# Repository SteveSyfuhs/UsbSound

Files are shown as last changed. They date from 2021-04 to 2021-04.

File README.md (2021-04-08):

# Usb Sound
 A custom-made USB sound card for Balanced Audio.

# Why?

My current USB DAC isn't great and instead of just buying a new one I thought I'd try and waste some serious engineering hours learning how to build one instead.

# What's wrong with the current DAC?

My existing DAC uses the [PCM2705](https://www.ti.com/lit/ds/symlink/pcm2705.pdf) chip to handle both the USB and DAC side of things. It's fine, I guess, but it has some annoying quirks.

First, you have to bolt on an additional chip to do silly things like control the USB descriptors. Absent that you're left with this annoying string with two trailing spaces (probably nulls?). Clearly not the end of the world, but I might as well aim for perfect.



Second, the output from the chip is only single-ended so it requires extra effort to make a _good_ differential output. This existing device is using a transformer (two, on per channel) to generate the differential pair, which is great for isolation, but transformers are notorious for distortion at high frequency. 

Curiously this device also doesn't produce a great differential output at 1000hz.



Channel A (blue) is the positive leg and Channel B (red) is the negative leg. Channel 3 (magenta?) is A+B, which ideally should sum to zero, not ~16mV RMS.

# Why are you using X?

To be clear: I really have no idea what I'm doing so my choice of parts or circuit are driven by the last thing I learned about. If there's clearly a better way to do something then please let me know.

### Why the STM32F4 Micro?

It happened to be the chip used in [Phil's video](https://www.youtube.com/watch?v=C7-8nUU6e3E) where learned to use Kicad and it happens to support I2S. It's incredibly powerful for the use case here, and a less powerful device could be used instead. That said, it could make for a useful platform for building out digital filters and stuff.

### Why the [PCM1795](https://www.ti.com/lit/ds/symlink/pcm1795.pdf) DAC?

I like the low distortion and noise floor it provides and since I'm starting with a blank canvas why not start with something that's overkill? I can only make it worse.

Note: the _audible_ differences between this and other DACs is ultimately going to be nil so there will be no notable benefit. I'm doing this because I can.

### Why the [NE5524](https://www.ti.com/lit/ds/symlink/ne5534.pdf) Op-Amps?

The PCM1795 uses that as a baseline for the measured circuits so it's a helpful starting place. I will probably switch these out for [LM4562's](https://www.ti.com/lit/ds/symlink/lm4562.pdf) in the near future once I test out the board and do initial measurements to compare against spec. The LM4562s have lower distortion and noise floor, and more interestingly contain two op-amps in the package so I can reduce the circuit footprint.

Again, I can only make things worse.

### Why Balanced Audio?

The speakers I'll be driving are studio monitors and they require a balanced XLR connection.

## Are you going to support multiple output channels?

Eventually, probably. The micro supports 3 I2S lines, and each I2S line supports two channels out and one in.

## Are you going to support audio in?

Maybe. See the output section.

## What's the driver story?

Ideally it'll show up as a USB audio device and all major operating systems will just pick it up.

# Measurement Methodology

A work in progress. Ideal testing should measure:

 * Noise - Specifically what the device adds to the signal.
 * Distortion - Specifically how the device modifies the signal integrity across the device bandwidth.
 * Flatness - Specifically whether the device has amplified or attenuated voltage across the device bandwidth.

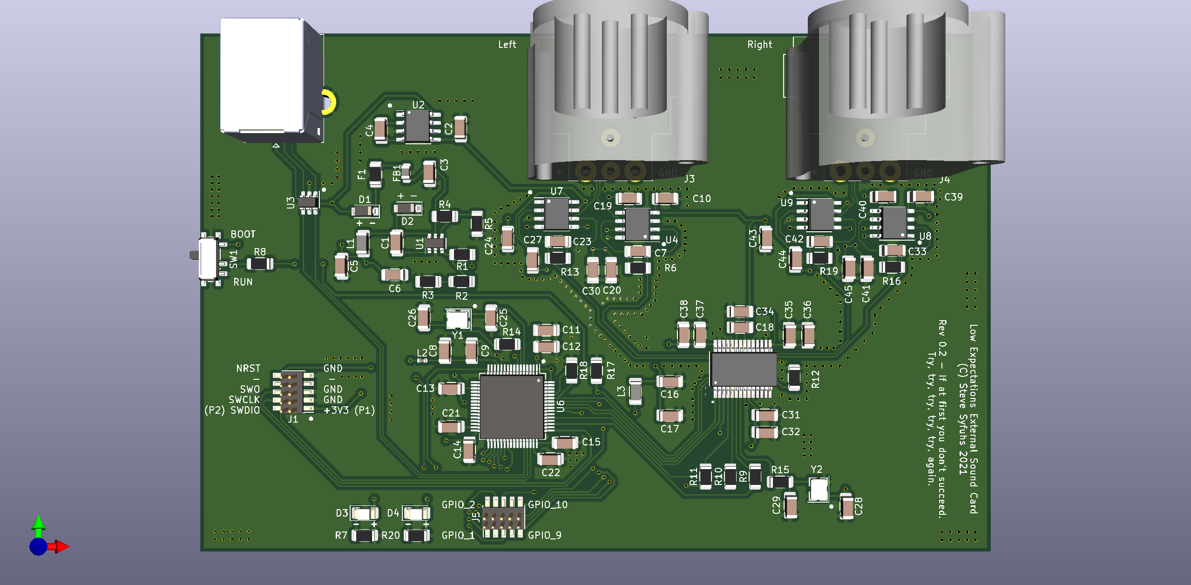
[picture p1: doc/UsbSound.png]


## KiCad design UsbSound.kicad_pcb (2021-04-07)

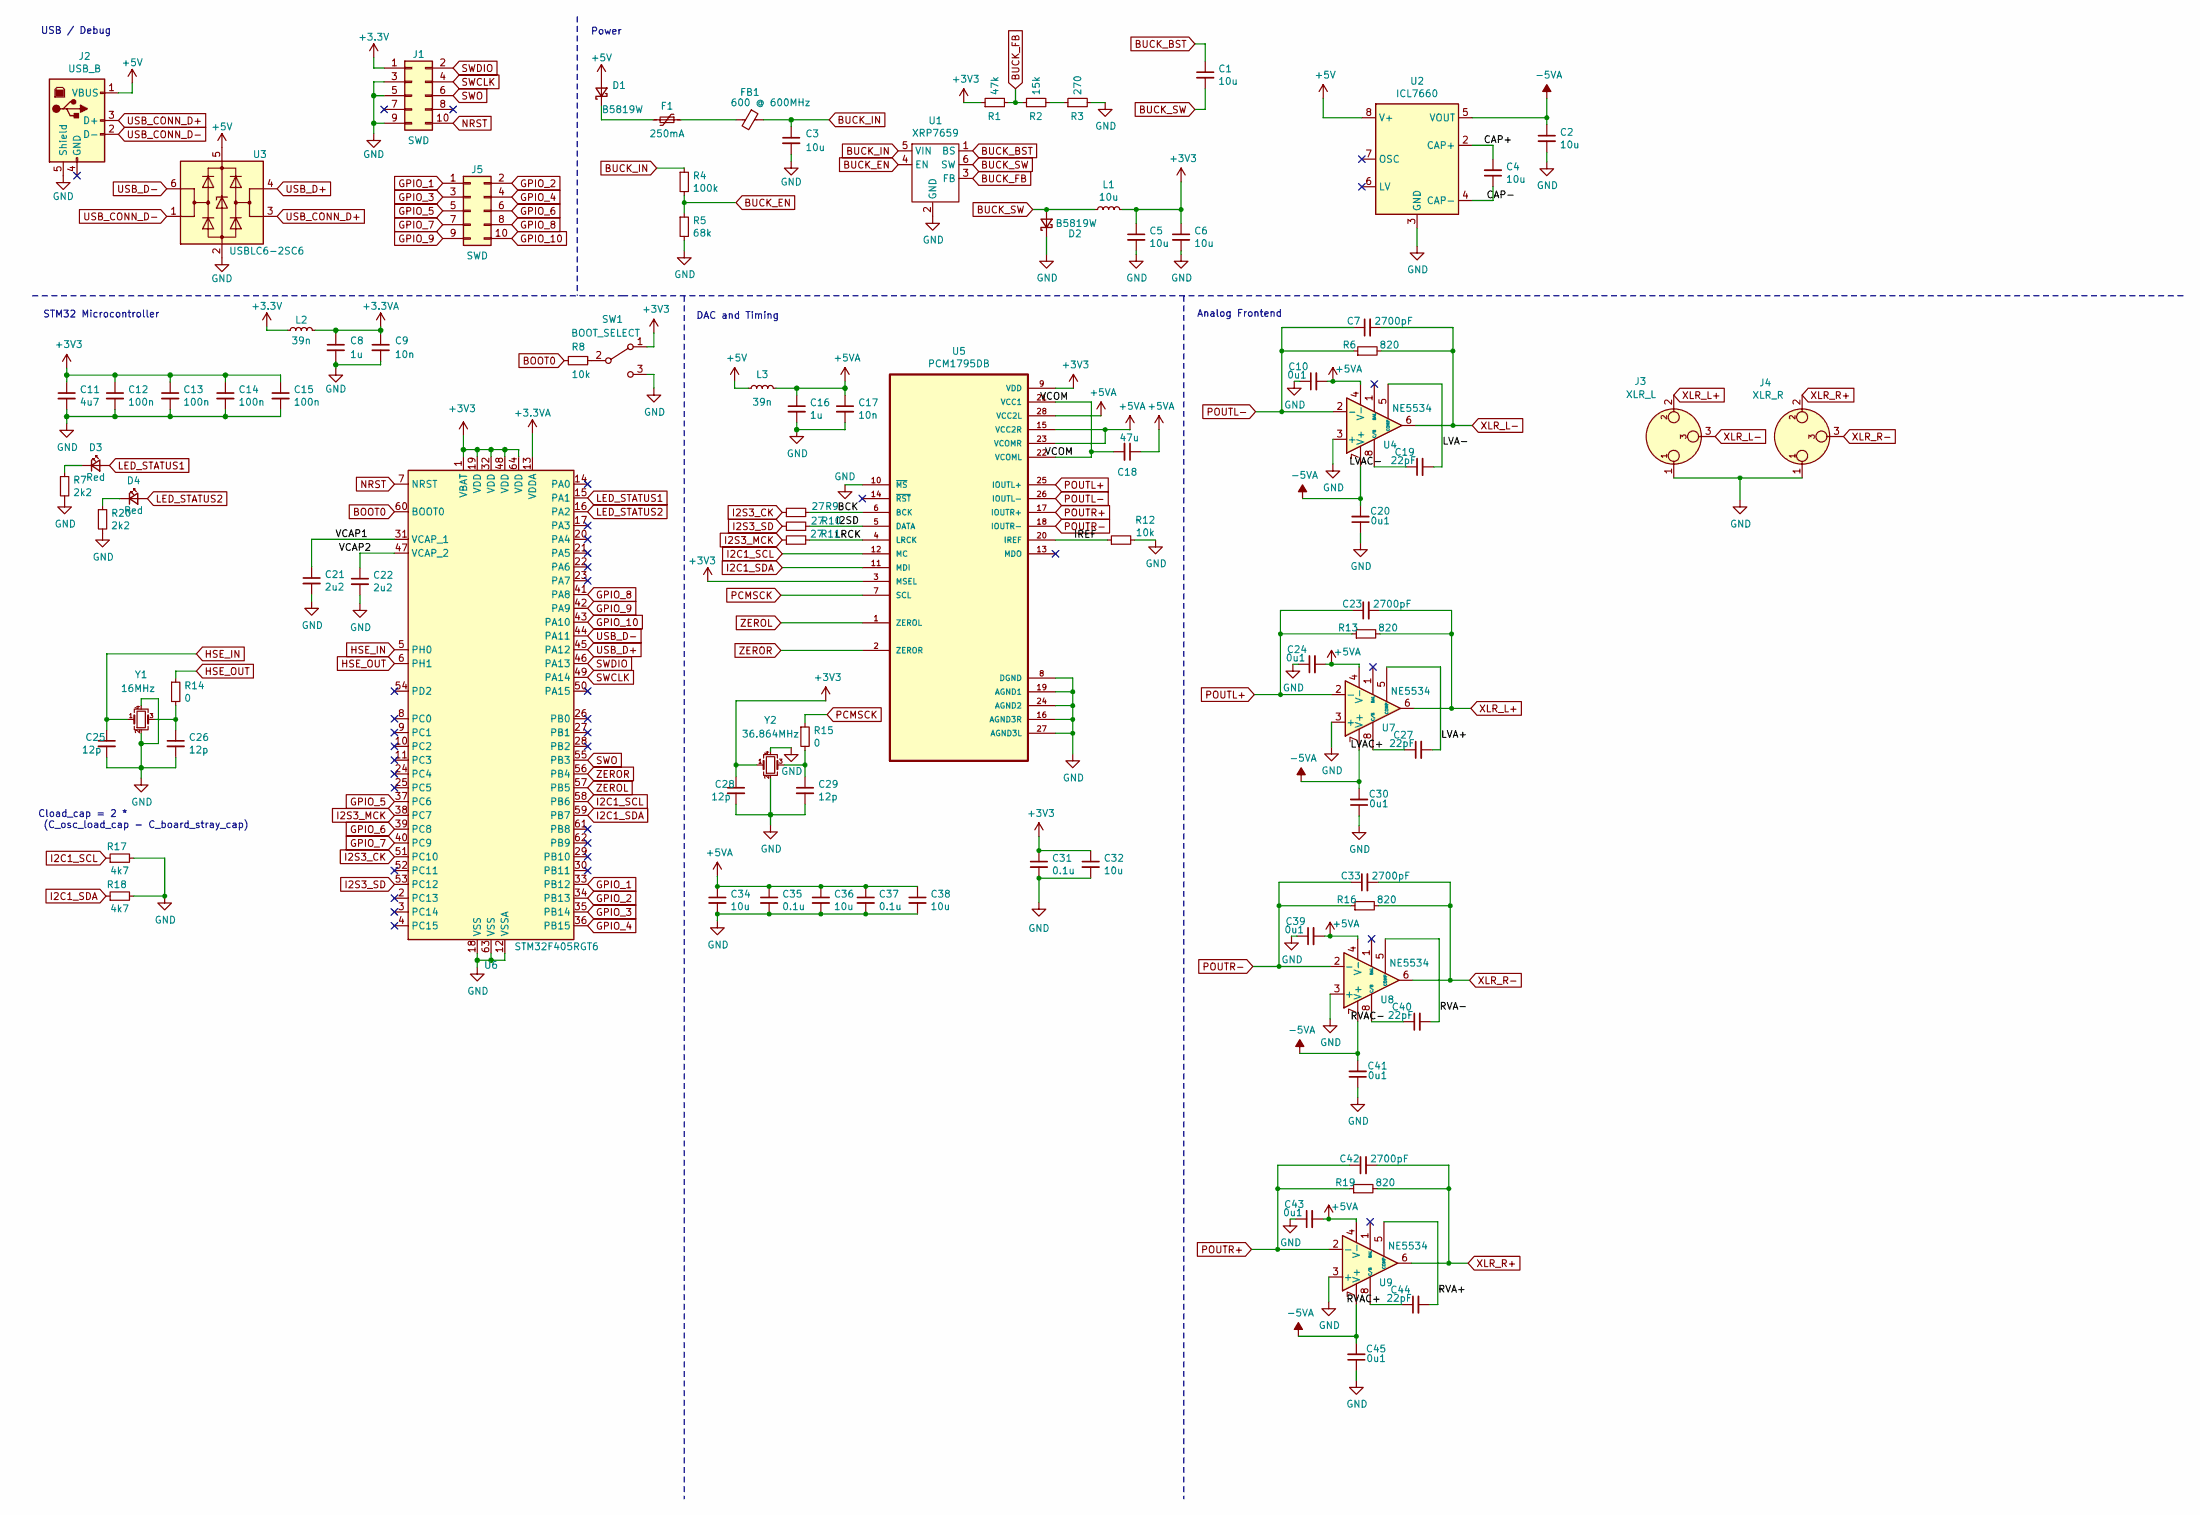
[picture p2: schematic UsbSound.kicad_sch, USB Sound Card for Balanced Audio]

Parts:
C1, C2, C4, C5, C6, C32, C34, C36, C38: 10u; C_1206_3216Metric
C3: 10u; C_1206_3216Metric; LCSC Part # C13585
C7, C23, C33, C42: 2700pF; C_1206_3216Metric
C8: 1u; C_1206_3216Metric; LCSC Part # C52923
C9: 10n; C_1206_3216Metric; LCSC Part # C15195
C10, C20, C24, C30, C39, C41, C43, C45: 0u1; C_1206_3216Metric
C11: 4u7; C_1206_3216Metric
C12, C13, C14, C15: 100n; C_1206_3216Metric
C16: 1u; C_1206_3216Metric
C17: 10n; C_1206_3216Metric
C18: 47u; C_1206_3216Metric
C19, C27, C40, C44: 22pF; C_1206_3216Metric
C21, C22: 2u2; C_1206_3216Metric
C25, C26, C28, C29: 12p; C_1206_3216Metric
C31, C35, C37: 0.1u; C_1206_3216Metric
D1: B5819W; D_SOD-123; LCSC Part # C8598
D2: B5819W; D_SOD-123
D3, D4: Red; LED_1206_3216Metric
F1: 250mA; Fuse_1206_3216Metric; LCSC Part # C369159
FB1: 600 @ 600MHz; L_0805_2012Metric; LCSC Part # C1017
J1, J5: SWD; PinHeader_2x05_P1.27mm_Vertical_SMD
J2: USB_B; USB_B_Lumberg_2411_02_Horizontal
J3: XLR_L; Jack_XLR_Neutrik_NC3MAH_Horizontal
J4: XLR_R; Jack_XLR_Neutrik_NC3MAH_Horizontal
L1: 10u; L_1206_3216Metric
L2: 39n; L_0402_1005Metric; LCSC Part # C26443
L3: 39n; L_1206_3216Metric
R1: 47k; R_1206_3216Metric
R2: 15k; R_1206_3216Metric
R3: 270; R_1206_3216Metric
R4: 100k; R_1206_3216Metric
R5: 68k; R_1206_3216Metric
R6, R13, R16, R19: 820; R_1206_3216Metric
R7, R20: 2k2; R_1206_3216Metric
R8, R12: 10k; R_1206_3216Metric
R9, R10, R11: 27; R_1206_3216Metric
R14, R15: 0; R_1206_3216Metric
R17, R18: 4k7; R_1206_3216Metric
SW1: BOOT_SELECT; SW_SPDT_PCM12
U1: XRP7659; TSOP-6_1.65x3.05mm_P0.95mm
U2: ICL7660; SOIC-8-1EP_3.9x4.9mm_P1.27mm_EP2.29x3mm
U3: USBLC6-2SC6; SOT-23-6; LCSC Part # C7519
U4, U7, U8, U9: NE5534; SOIC-8-1EP_3.9x4.9mm_P1.27mm_EP2.29x3mm
U5: PCM1795DB; SOP65P780X200-28N
U6: STM32F405RGT6; LQFP-64_10x10mm_P0.5mm
Y1: 16MHz; Crystal_SMD_3225-4Pin_3.2x2.5mm
Y2: 36.864MHz; Crystal_SMD_3225-4Pin_3.2x2.5mm

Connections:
+3.3VA: C8.1, C9.1, L2.2, U6.13 (VDDA)
+5V: D1.2 (A), J2.1 (VBUS), L3.1, U2.8 (V+), U3.5 (VBUS)
+5VA: C10.2, C16.1, C17.1, C18.1, C24.2, C34.1, C35.1, C36.1, C37.1, C38.1, C39.2, C43.2, L3.2, U4.4 (V-), U5.15 (VCC2R), U5.23 (VCOMR), U5.28 (VCC2L), U7.4 (V-), U8.4 (V-), U9.4 (V-)
-5VA: C2.1, C20.2, C30.2, C41.2, C45.2, U2.5 (VOUT), U4.7 (V+), U7.7 (V+), U8.7 (V+), U9.7 (V+)
/BCK: R9.2, U5.6 (BCK)
/CAP+: C4.2, U2.2 (CAP+)
/CAP-: C4.1, U2.4 (CAP-)
/I2SD: R10.2, U5.5 (DATA)
/IREF: R12.1, U5.20 (IREF)
/LRCK: R11.2, U5.4 (LRCK)
/LVA+: C27.2, U7.5 (COMP)
/LVA-: C19.2, U4.5 (COMP)
/LVAC+: C27.1, U7.8 (C/B)
/LVAC-: C19.1, U4.8 (C/B)
/RVA+: C44.2, U9.5 (COMP)
/RVA-: C40.2, U8.5 (COMP)
/RVAC+: C44.1, U9.8 (C/B)
/RVAC-: C40.1, U8.8 (C/B)
/VCAP1: C21.1, U6.31 (VCAP_1)
/VCAP2: C22.1, U6.47 (VCAP_2)
/VCOM: C18.2, U5.21 (VCC1), U5.22 (VCOML)
BOOT0: R8.2, U6.60 (BOOT0)
BUCK_BST: C1.1, U1.1 (BS)
BUCK_EN: R4.2, R5.1, U1.4 (EN)
BUCK_FB: R1.2, R2.1, U1.3 (FB)
BUCK_IN: C3.1, FB1.1, R4.1, U1.5 (VIN)
BUCK_SW: C1.2, D2.2 (A), L1.1, U1.6 (SW)
GND: C2.2, C3.2, C5.2, C6.2, C8.2, C9.2, C10.1, C11.2, C12.2, C13.2, C14.2, C15.2, C16.2, C17.2, C20.1, C21.2, C22.2, C24.1, C25.2, C26.2, C28.2, C29.2, C30.1, C31.2, C32.2, C34.2, C35.2, C36.2, C37.2, C38.2, C39.1, C41.1, C43.1, C45.1, D2.1 (K), J1.3, J1.5, J1.9, J2.5 (Shield), J3.1, J4.1, R3.2, R5.2, R7.2, R12.2, R17.2, R18.2, R20.2, SW1.3 (C), U1.2 (GND), U2.3 (GND), U3.2 (GND), U4.3 (+), U5.8 (DGND), U5.10 (~MS), U5.16 (AGND3R), U5.19 (AGND1), U5.24 (AGND2), U5.27 (AGND3L), U6.12 (VSSA), U6.18 (VSS), U6.63 (VSS), U7.3 (+), U8.3 (+), U9.3 (+), Y1.2, Y1.4, Y2.2, Y2.4
GPIO_1: J5.1, U6.33 (PB12)
GPIO_2: J5.2, U6.34 (PB13)
GPIO_3: J5.3, U6.35 (PB14)
GPIO_4: J5.4, U6.36 (PB15)
GPIO_5: J5.5, U6.37 (PC6)
GPIO_6: J5.6, U6.39 (PC8)
GPIO_7: J5.7, U6.40 (PC9)
GPIO_8: J5.8, U6.41 (PA8)
GPIO_9: J5.9, U6.42 (PA9)
GPIO_10: J5.10, U6.43 (PA10)
HSE_IN: C25.1, U6.5 (PH0), Y1.1
HSE_OUT: R14.1, U6.6 (PH1)
I2C1_SCL: R17.1, U5.12 (MC), U6.58 (PB6)
I2C1_SDA: R18.1, U5.11 (MDI), U6.59 (PB7)
I2S3_CK: R9.1, U6.51 (PC10)
I2S3_MCK: R11.1, U6.38 (PC7)
I2S3_SD: R10.1, U6.53 (PC12)
LED_STATUS1: D3.2 (A), U6.15 (PA1)
LED_STATUS2: D4.2 (A), U6.16 (PA2)
NRST: J1.10, U6.7 (NRST)
unnamed: C26.1, R14.2, Y1.3
unnamed: C29.1, R15.2, Y2.3
unnamed: D1.1 (K), F1.2
unnamed: D3.1 (K), R7.1
unnamed: D4.1 (K), R20.1
unnamed: F1.1, FB1.2
unnamed: R2.2, R3.1
unnamed: R8.1, SW1.2 (B)
PCMSCK: R15.1, U5.7 (SCL)
POUTL+: C23.1, R13.1, U5.25 (IOUTL+), U7.2 (-)
POUTL-: C7.1, R6.1, U4.2 (-), U5.26 (IOUTL-)
POUTR+: C42.1, R19.1, U5.17 (IOUTR+), U9.2 (-)
POUTR-: C33.1, R16.1, U5.18 (IOUTR-), U8.2 (-)
SWCLK: J1.4, U6.49 (PA14)
SWDIO: J1.2, U6.46 (PA13)
SWO: J1.6, U6.55 (PB3)
USB_CONN_D+: J2.3 (D+), U3.3 (I/O2)
USB_CONN_D-: J2.2 (D-), U3.1 (I/O1)
USB_D+: U3.4 (I/O2), U6.45 (PA12)
USB_D-: U3.6 (I/O1), U6.44 (PA11)
XLR_L+: C23.2, J3.2, R13.2, U7.6
XLR_L-: C7.2, J3.3, R6.2, U4.6
XLR_R+: C42.2, J4.2, R19.2, U9.6
XLR_R-: C33.2, J4.3, R16.2, U8.6
ZEROL: U5.1 (ZEROL), U6.57 (PB5)
ZEROR: U5.2 (ZEROR), U6.56 (PB4)

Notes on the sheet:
Cload_cap = 2 * (C_osc_load_cap - C_board_stray_cap)
USB / Debug
STM32 Microcontroller
Power
DAC and Timing
Analog Frontend

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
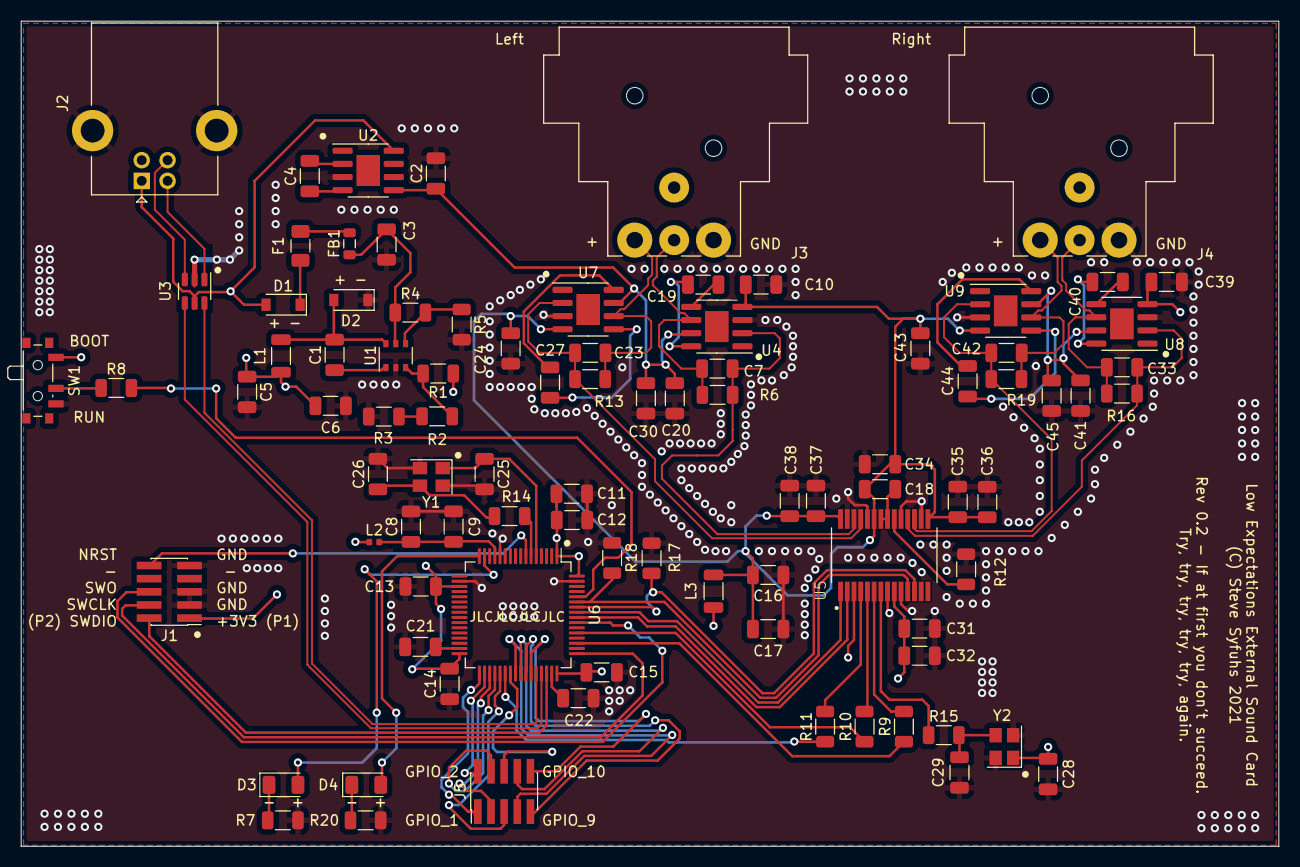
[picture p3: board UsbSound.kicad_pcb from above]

Board: 4 copper layers, 121.6 x 79.8 mm, 91 parts (0 on the bottom side), 75 nets.

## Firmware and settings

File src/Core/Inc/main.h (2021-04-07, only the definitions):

#define ZEROR_Pin GPIO_PIN_4
#define ZEROR_GPIO_Port GPIOB
#define ZEROL_Pin GPIO_PIN_5
#define ZEROL_GPIO_Port GPIOB

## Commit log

2021-03-30 first pass at schematic.
    Basic USB to micro to DAC to XLR stereo.
    DAC clock needs to be added.
    Power rails for opamps maybe should be boosted.
    [UsbSound.kicad_pcb, UsbSound.kicad_sch]
2021-04-01 fixup electrical rules and stupid grids
    Added crystal for PCM clock.
    Added footprints for most components.
    [UsbSound.kicad_sch]
2021-04-03 First rev of board is done
    If at first you don't succeed... try...try...try...try...try...try...try...try...
    [UsbSound.kicad_pcb, UsbSound.kicad_sch]
2021-04-03 Added rev 0.1 fabrication files
    [UsbSound-B_Cu.gbr, UsbSound-B_Mask.gbr, UsbSound-B_Paste.gbr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]
2021-04-03 Added -5v rail because I'm an idiot and forgot it
    [UsbSound.kicad_pcb, UsbSound.kicad_sch]
2021-04-03 Op Amps are better paired for line matching
    [UsbSound.kicad_pcb]
2021-04-04 Fixing models
    [UsbSound.kicad_pcb, UsbSound.kicad_sch]
2021-04-04 More via stitching and updated image
    [UsbSound.kicad_pcb]
2021-04-07 Maybe fixed clock path. Moved some power routes to avoid analog signal.
    Added some additional silkscreen for useful text.
    [UsbSound.kicad_pcb, UsbSound.kicad_sch]
2021-04-07 Added GPIO pin header for future testing
    [UsbSound.kicad_pcb, UsbSound.kicad_sch]

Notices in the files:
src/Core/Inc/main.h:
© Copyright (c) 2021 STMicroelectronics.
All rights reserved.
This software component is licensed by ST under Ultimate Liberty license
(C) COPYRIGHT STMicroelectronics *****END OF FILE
